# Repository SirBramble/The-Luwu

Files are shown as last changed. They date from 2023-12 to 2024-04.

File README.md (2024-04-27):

# The Luwu

ESP32 Board for RGB LED integration into Home Assistant
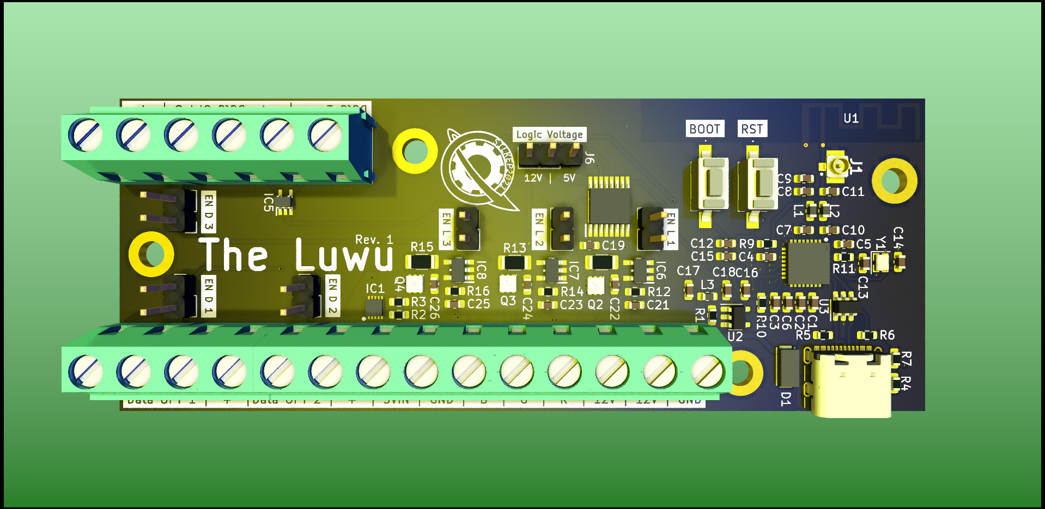
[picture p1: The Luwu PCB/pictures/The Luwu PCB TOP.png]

## Motivation

My 3D Printer has a standard RGB LED Strip installed in its enclosure. This Board allows me to control it with Home Assistant. There are easier and cheaper ways of doing this, but this Board also doubled as a test board for implementing Ideal Diodes and MOSFET drivers.

## Features

The Board uses a ESP32C3 to interface with Home Assistant. The ESP controls 3 RGB channels that are each capable of (in theory) driving 10A. These channels can also be mapped to control addressable RGB Strips, although this can only be done for all channels at once and **ONLY** if the level shifter logic voltage is set to 5V. There is also one dedicated addressable RGB Strip Port, that can be used at any time.

To accomplish these features, it needs a 5V supply to drive the logic and optionally the addressable LED Strips and a 12V supply to drive the non addressable Strip. To accomplish this in a 3D Printer environment a Voltage converter for the 24V Power Supply is needed. For this [the Supluwu](https://github.com/SirBramble/The-Supluwu) could be used.

## Integration into Home Assistant

ESP Home Config:

```yaml
esphome:
  name: NAME
  friendly_name: FRIENDLY_NAME

esp32:
  board: esp32-c3-devkitm-1
  framework:
    type: arduino

# Enable logging
logger:
  level: DEBUG
# Enable Home Assistant API
api:
  encryption:
    key: ""     #let this auto generate or set it yourself

ota:
  password: ""  #let this auto generate or set it yourself

wifi:
  ssid: !secret wifi_ssid
  password: !secret wifi_password

  # Enable fallback hotspot (captive portal) in case wifi connection fails
  ap:
    ssid: "FALLBACK_HOTSPOT_NAME"
    password: "SUPER_SECURE_PASSWORD123"

light:
  - platform: rgb
    id: oldstyle_rgb
    name: "Oldstyle RGB"
    red: gpio_red
    green: gpio_green
    blue: gpio_blue
    effects:
      - lambda:
          name: Rainbow
          update_interval: 5s
          lambda: |-
            static int state = 0;
            auto call = id(oldstyle_rgb).turn_on();
            call.set_transition_length(4000);
            if (state == 0) {
              call.set_rgb(1.0, 0.0, 0.0);
            } else if (state == 1) {
              call.set_rgb(1.0, 0.5, 0.0);
            } else if (state == 2) {
              call.set_rgb(1.0, 1.0, 0.0);
            } else if (state == 3) {
              call.set_rgb(0.5, 1.0, 0.0);
            } else if (state == 4) {
              call.set_rgb(0.0, 1.0, 0.0);
            } else if (state == 5) {
              call.set_rgb(0.0, 1.0, 0.5);
            } else if (state == 6) {
              call.set_rgb(0.0, 1.0, 1.0);
            } else if (state == 7) {
              call.set_rgb(0.0, 0.5, 1.0);
            } else if (state == 8) {
              call.set_rgb(0.0, 0.0, 1.0);
            } else if (state == 9) {
              call.set_rgb(0.5, 0.0, 1.0);
            } else if (state == 10) {
              call.set_rgb(1.0, 0.0, 1.0);
            } else if (state == 11) {
              call.set_rgb(1.0, 0.0, 0.5);
            }
            call.perform();
            state++;
            if (state == 12)
              state = 0;
      - lambda:
            name: Fast Rainbow
            update_interval: 1s
            lambda: |-
              static int state = 0;
              auto call = id(oldstyle_rgb).turn_on();
              call.set_transition_length(1000);
              if (state == 0) {
                call.set_rgb(1.0, 0.0, 0.0);
              } else if (state == 1) {
                call.set_rgb(1.0, 0.5, 0.0);
              } else if (state == 2) {
                call.set_rgb(1.0, 1.0, 0.0);
              } else if (state == 3) {
                call.set_rgb(0.5, 1.0, 0.0);
              } else if (state == 4) {
                call.set_rgb(0.0, 1.0, 0.0);
              } else if (state == 5) {
                call.set_rgb(0.0, 1.0, 0.5);
              } else if (state == 6) {
                call.set_rgb(0.0, 1.0, 1.0);
              } else if (state == 7) {
                call.set_rgb(0.0, 0.5, 1.0);
              } else if (state == 8) {
                call.set_rgb(0.0, 0.0, 1.0);
              } else if (state == 9) {
                call.set_rgb(0.5, 0.0, 1.0);
              } else if (state == 10) {
                call.set_rgb(1.0, 0.0, 1.0);
              } else if (state == 11) {
                call.set_rgb(1.0, 0.0, 0.5);
              }
              call.perform();
              state++;
              if (state == 12)
                state = 0;

# Example output entry (default)
output:
  - platform: ledc
    id: gpio_red
    pin: GPIO6
  - platform: ledc
    id: gpio_green
    pin: GPIO7
  - platform: ledc
    id: gpio_blue
    pin: GPIO10

#uncomment to enable
# Example output entry (modified)
#output:
#  - platform: ledc
#    id: gpio_red
#    pin: GPIO7
#  - platform: ledc
#    id: gpio_green
#    pin: GPIO10
#  - platform: ledc
#    id: gpio_blue
#    pin: GPIO6

captive_portal:
    
```

### Flashing firmware

I had some issues when flashing the Firmware.

This helped: [https://github.com/espressif/esp-idf/issues/9005](https://github.com/espressif/esp-idf/issues/9005)

## Schematic

The Schematic can be found here: [The Luwu PCB/print/The Luwu PCB.pdf](https://github.com/SirBramble/The-Luwu/blob/f4439437ab35bf7dc6665ce1337c5cff792b409b/The%20Luwu%20PCB/print/The%20Luwu%20PCB.pdf)

## Pictures



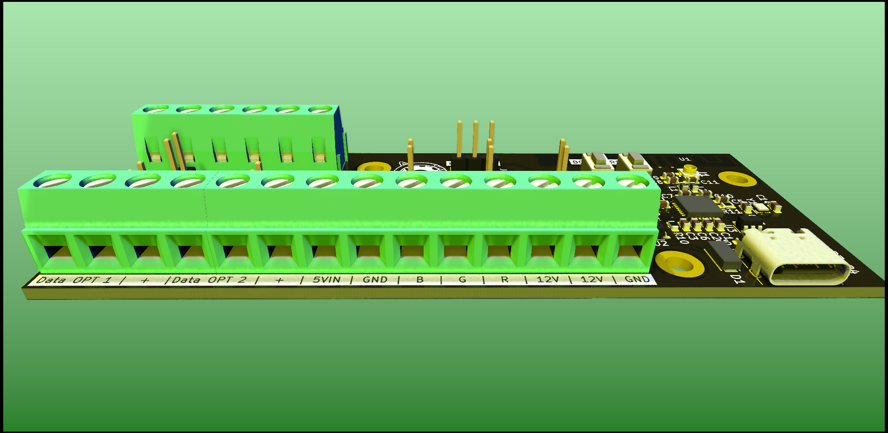
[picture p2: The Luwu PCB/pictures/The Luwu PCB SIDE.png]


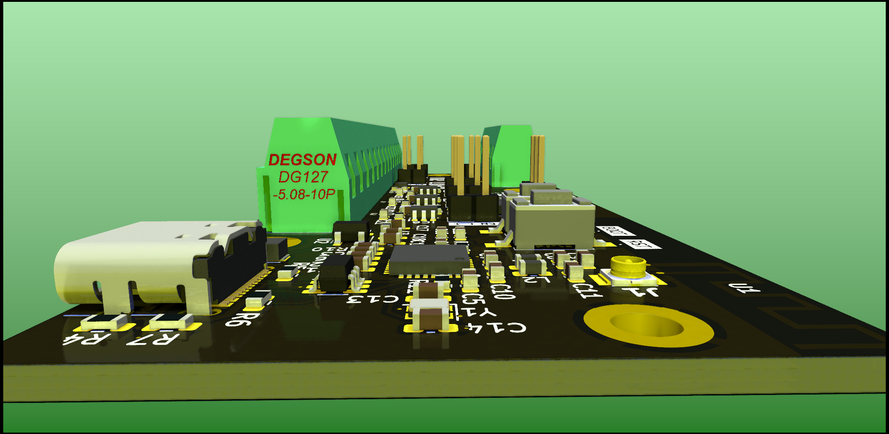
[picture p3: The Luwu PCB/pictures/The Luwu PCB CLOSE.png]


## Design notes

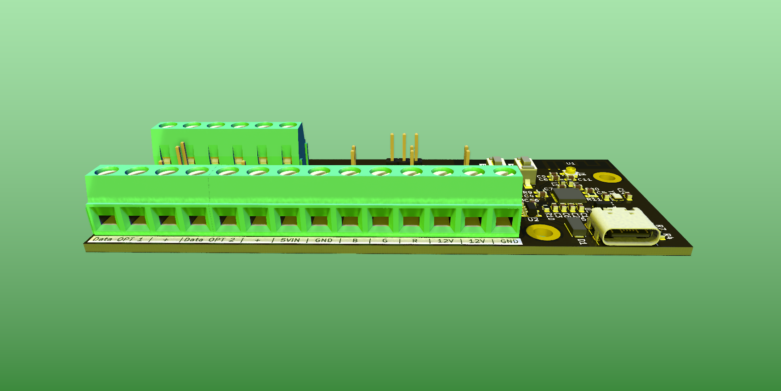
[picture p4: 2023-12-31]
The Luwu PCB/pictures/The Luwu PCB TN.png

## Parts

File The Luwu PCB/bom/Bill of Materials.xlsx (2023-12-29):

Designator | Footprint | Value | Description | Part Nr. | Quantity | Price/pcs. | Price
C10, C11 | 0603 | 3p3 | +/-0.5pF 50V Capacitor | 710-885012006048 (https://www.mouser.de/ProductDetail/710-885012006048) | 2 | 0.09 € | 0.19 €
C12, C15, C17, C18, C19, C2, C4, C5, C6, C7, C8 | 0603 | 100n | Generic 5% Capacitor | Generic | 11 | 0.01 € | 0.11 €
C13, C14 | 0603 | 10p | 5% 25V Capacitor | 710-885012006032 (https://www.mouser.de/ProductDetail/710-885012006032) | 2 | 0.09 € | 0.19 €
C16 | 0603 | 1u | Generic 20% Capacitor | Generic | 1 | 0.05 € | 0.05 €
C1, C3, C9, C21, C23, C25 | 0603 | 10uF | Generic 20% Capacitor | Generic | 6 | 0.05 € | 0.30 €
C22, C24, C26 | 0603 | 100nF | Generic 5% Capacitor | Generic | 3 | 0.01 € | 0.03 €
D1 | CD214A-B240LR | CD214A-B240LR | 40V 2A Diode | 652-CD214A-B240LR (https://www.mouser.de/ProductDetail/Bourns/CD214A-B240LR?qs=f9yNj16SXrLocD1dV%2FObRw%3D%3D) | 1 | 0.39 € | 0.39 €
IC1 | SON40P200X200X80-11N | TPS22953DSQR | Leistungsschalter IC | 595-TPS22953DSQR (https://www.mouser.de/ProductDetail/Texas-Instruments/TPS22953DSQR?qs=lGsJEpdjMw3By0yQoF%252B7vQ%3D%3D) | 1 | 0.77 € | 0.77 €
IC2 | QFN50P500X500X90-33N-D | ESP32-C3FH4 | ESP32C3 | 356-ESP32-C3FH4 (https://www.mouser.de/ProductDetail/Espressif-Systems/ESP32-C3FH4?qs=iLbezkQI%252BsgL5PSvEueYlQ%3D%3D) | 1 | 1.21 € | 1.21 €
IC4 | SOP65P640X120-16N | CD40109BPWR | 4-Bit Level shifter | 595-CD40109BPWR (https://www.mouser.de/ProductDetail/Texas-Instruments/CD40109BPWR?qs=LzFo6vGRJ4uizAk1qQcvPQ%3D%3D) | 1 | 0.44 € | 0.44 €
IC5 | SOT65P210X110-5N | SN74LV1T04DCKRG4 | 1-Bit Level shifter | 595-SN74LV1T04DCKRG4 (https://www.mouser.de/ProductDetail/Texas-Instruments/SN74LV1T04DCKRG4?qs=qSfuJ%252Bfl%2Fd4at7O15qky6A%3D%3D) | 1 | 0.21 € | 0.21 €
IC6, IC7, IC8 | SOT95P280X145-5N | UCC27519DBVR | Gate driver | 595-UCC27519DBVR (https://www.mouser.de/ProductDetail/Texas-Instruments/UCC27519DBVR?qs=Zv8nmyeoaKte1PBX4a6EXg%3D%3D) | 3 | 0.77 € | 2.32 €
J1 | 23370191 | 2337019-1 | MicroCoax connector | 571-2337019-1 (https://www.mouser.de/ProductDetail/TE-Connectivity/2337019-1?qs=l4Gc20tDgJIuN7nS9rJkJw%3D%3D) | 1 | 0.21 € | 0.21 €
J10 | TerminalBlock_bornier-3_P5.08mm | Neopixel Terminal out 3 | Generic Terminal Block | Generic | 1 | 0.05 € | 0.05 €
J2 | USB_C_Receptacle_GCT_USB4105-xx-A_16P_TopMnt_Horizontal | USB_C_Receptacle_USB2.0 | USB Type C 2.0 | 640-USB4105-GF-A (https://www.mouser.de/ProductDetail/640-USB4105-GF-A) | 1 | 0.74 € | 0.74 €
J3 | TerminalBlock_bornier-2_P5.08mm | 5V_IN | Generic Terminal Block | Generic | 1 | 0.05 € | 0.05 €
J4 | TerminalBlock_bornier-3_P5.08mm | Neopixel Terminal opt 1 | Generic Terminal Block | Generic | 1 | 0.05 € | 0.05 €
J5 | TerminalBlock_bornier-2_P5.08mm | 12V_IN | Generic Terminal Block | Generic | 1 | 0.05 € | 0.05 €
J6 | PinHeader_1x03_P2.54mm_Vertical | V SEL LS | Generic Pin Header | Generic | 1 | 0.05 € | 0.05 €
J7 | TerminalBlock_bornier-4_P5.08mm | Screw_Terminal_01x04 | Generic Terminal Block | Generic | 1 | 0.05 € | 0.05 €
J8 | TerminalBlock_bornier-3_P5.08mm | Neopixel Terminal | Generic Terminal Block | Generic | 1 | 0.05 € | 0.05 €
J9 | TerminalBlock_bornier-3_P5.08mm | Neopixel Terminal opt 2 | Generic Terminal Block | Generic | 1 | 0.05 € | 0.05 €
JP1, JP2, JP3, JP4, JP5, JP6 | PinHeader_1x02_P2.54mm_Vertical | Jumper_2_Open | Generic Pin Header | Generic | 6 | 0.05 € | 0.30 €
L1, L2, L3 | 0603 | 2n2 | 300mA 0,1ohm Inductor | 710-7847805220 (https://www.mouser.de/ProductDetail/710-7847805220) | 3 | 0.09 € | 0.28 €
Q2, Q3, Q4 | BUK7D2540EX | BUK7D25-40EX | N-MOSFET | 771-BUK7D25-40EX (https://eu.mouser.com/ProductDetail/Nexperia/BUK7D25-40EX?qs=%252BEew9%252B0nqrD3pISD4vyDrQ%3D%3D) | 3 | 0.25 € | 0.75 €
R1, R12, R14, R16 | 0603 | 10k | Generic 1% Resistor | Generic | 4 | 0.02 € | 0.08 €
R10, R5, R6, R9 | 0603 | 5k1 | Generic 1% Resistor | Generic | 4 | 0.02 € | 0.08 €
R11 | 0603 | 22 | 1% Resistor | 603-RC0603FR-1022RL (https://www.mouser.de/ProductDetail/603-RC0603FR-1022RL) | 1 | 0.09 € | 0.09 €
R13, R15, R8 | 1206 | 1.5 | Current shunt / Impulse limmiter | 652-CRM1206FX1R50ELF (https://www.mouser.de/ProductDetail/652-CRM1206FX1R50ELF) | 3 | 0.38 € | 1.14 €
R2 | 0603 | 100k | Generic 1% Resistor | Generic | 1 | 0.02 € | 0.02 €
R3 | 0603 | 20k | 1% Resistor | 603-RT0603FRE0720KL (https://www.mouser.de/ProductDetail/YAGEO/RT0603FRE0720KL?qs=8cPjvKtxWv65BAftULaFAQ%3D%3D) | 1 | 0.09 € | 0.09 €
R4 | 0603 | 15k | 1% Resistor | 603-RT0603FRE1315KL (https://www.mouser.de/ProductDetail/YAGEO/RT0603FRE1315KL?qs=%2Ff7pOCXLR5e5m0uEnyCcoA%3D%3D) | 1 | 0.09 € | 0.09 €
R7 | 0603 | 22k | 1% Resistor | 603-RT0603FRE1322KL (https://www.mouser.de/ProductDetail/YAGEO/RT0603FRE1322KL?qs=uTWeqZe11vwzRdhBSFPFcQ%3D%3D) | 1 | 0.09 € | 0.09 €
SW1, SW2 | PTS636SP50SMTRLFS | PTS636 SP50 | Tact. Switch 12V 50mA | 611-PTS636SP50SMTRLF (https://www.mouser.de/ProductDetail/CK/PTS636-SP50-SMTR-LFS?qs=vLWxofP3U2yQrwr1QnrRJw%3D%3D) | 2 | 0.14 € | 0.28 €
U2 | SOT-23-5 | AP2112K-3.3 | 3V3 Voltage Regulator | 621-AP2112K-3.3TRG1 (https://www.mouser.de/ProductDetail/Diodes-Incorporated/AP2112K-3.3TRG1?qs=x6A8l6qLYDDPYHosCdzh%2FA%3D%3D) | 1 | 0.31 € | 0.31 €
U3 | SOT-23-6 | USBLC6-2SC6 | TVS Diode Usb | 511-USBLC6-2SC6 (https://www.mouser.de/ProductDetail/STMicroelectronics/USBLC6-2SC6?qs=po45yt2pPpu%2FhNIlwQdTlg%3D%3D) | 1 | 0.54 € | 0.54 €
Y1 | Crystal_SMD_2016-4Pin_2.0x1.6mm | ECS-400-10-37B2-CKM-TR | Crystal 40MHz 10pF | 520-400-10-37B2CKMTR (https://www.mouser.de/ProductDetail/ECS/ECS-400-10-37B2-CKM-TR?qs=QNEnbhJQKvYTTE6TC4Pr1w%3D%3D) | 1 | 0.35 € | 0.35 €
 |  |  |  |  |  |  | 12.07 €

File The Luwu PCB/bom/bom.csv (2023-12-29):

Designator | Footprint | Quantity | Value | LCSC Part #
C1, C3, C9 | 0603 | 3 | 10u
C10, C11 | 0603 | 2 | 3p3
C12, C15, C17, C18, C19, C2, C4, C5, C6, C7, C8 | 0603 | 11 | 100n
C13, C14 | 0603 | 2 | 10p
C16 | 0603 | 1 | 1u
C21, C23, C25 | 0603 | 3 | 10uF
C22, C24, C26 | 0603 | 3 | 100nF
D1 | CD214A-B240LR | 1 | CD214A-B240LR
IC1 | SON40P200X200X80-11N | 1 | TPS22953DSQR
IC2 | QFN50P500X500X90-33N-D | 1 | ESP32-C3FH4
IC4 | SOP65P640X120-16N | 1 | CD40109BPWR
IC5 | SOT65P210X110-5N | 1 | SN74LV1T04DCKRG4
IC6, IC7, IC8 | SOT95P280X145-5N | 3 | UCC27519DBVR
J1 | 23370191 | 1 | 2337019-1
J10 | TerminalBlock_bornier-3_P5.08mm | 1 | Neopixel Terminal out 3
J2 | USB_C_Receptacle_GCT_USB4105-xx-A_16P_TopMnt_Horizontal | 1 | USB_C_Receptacle_USB2.0
J3 | TerminalBlock_bornier-2_P5.08mm | 1 | 5V_IN
J4 | TerminalBlock_bornier-3_P5.08mm | 1 | Neopixel Terminal opt 1
J5 | TerminalBlock_bornier-2_P5.08mm | 1 | 12V_IN
J6 | PinHeader_1x03_P2.54mm_Vertical | 1 | V SEL LS
J7 | TerminalBlock_bornier-4_P5.08mm | 1 | Screw_Terminal_01x04
J8 | TerminalBlock_bornier-3_P5.08mm | 1 | Neopixel Terminal
J9 | TerminalBlock_bornier-3_P5.08mm | 1 | Neopixel Terminal opt 2
JP1, JP2, JP3, JP4, JP5, JP6 | PinHeader_1x02_P2.54mm_Vertical | 6 | Jumper_2_Open
L1, L2, L3 | 0603 | 3 | 2n2
Q2, Q3, Q4 | BUK7D2540EX | 3 | BUK7D25-40EX
R1, R12, R14, R16 | 0603 | 4 | 10k
R10, R5, R6, R9 | 0603 | 4 | 5k1
R11 | 0603 | 1 | 22
R13, R15, R8 | 1206 | 3 | 1.5
R2 | 0603 | 1 | 100k
R3 | 0603 | 1 | 20k
R4 | 0603 | 1 | 15k
R7 | 0603 | 1 | 22k
SW1, SW2 | PTS636SP50SMTRLFS | 2 | PTS636 SP50
U2 | SOT-23-5 | 1 | AP2112K-3.3
U3 | SOT-23-6 | 1 | USBLC6-2SC6
Y1 | Crystal_SMD_2016-4Pin_2.0x1.6mm | 1 | ECS-400-10-37B2-CKM-TR

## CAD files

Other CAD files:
The Luwu PCB/plot/The Luwu PCB-B_Silkscreen.dxf
The Luwu PCB/plot/The Luwu PCB-F_Silkscreen.dxf

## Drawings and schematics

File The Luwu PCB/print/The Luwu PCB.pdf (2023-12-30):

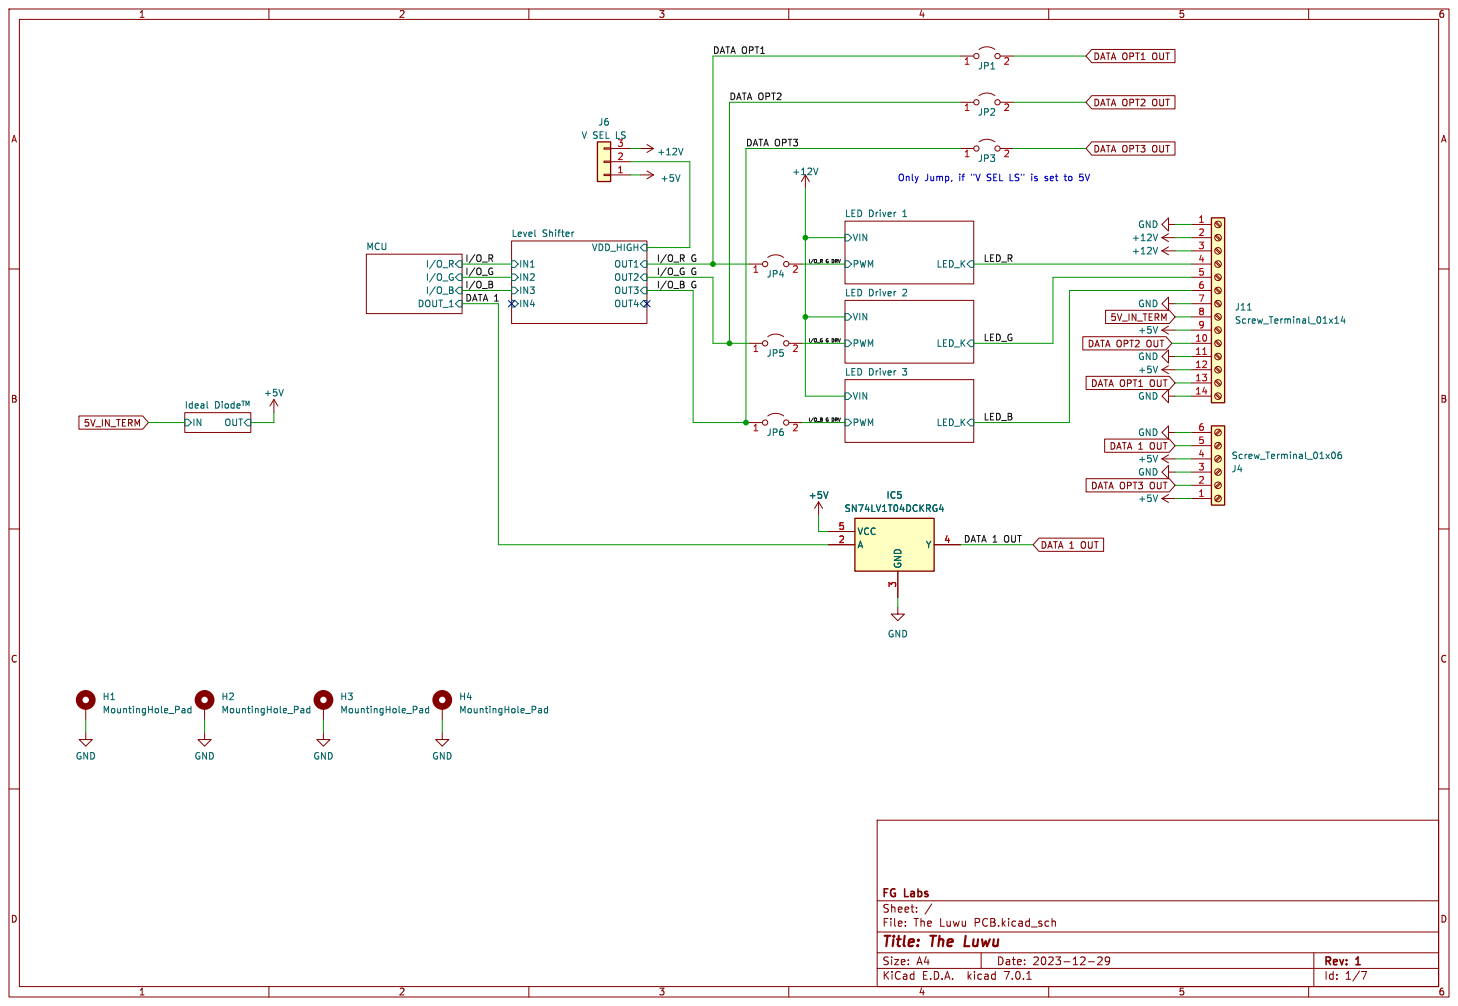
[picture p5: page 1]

DATA OPT1 OUT DATA OPT1 OUT DATA OPT3 OUT DATA OPT2 OUT

LED_B DATA 1 OUT Only Jump, if "V SEL LS" is set to 5V

Id: 1/7 Title: The Luwu

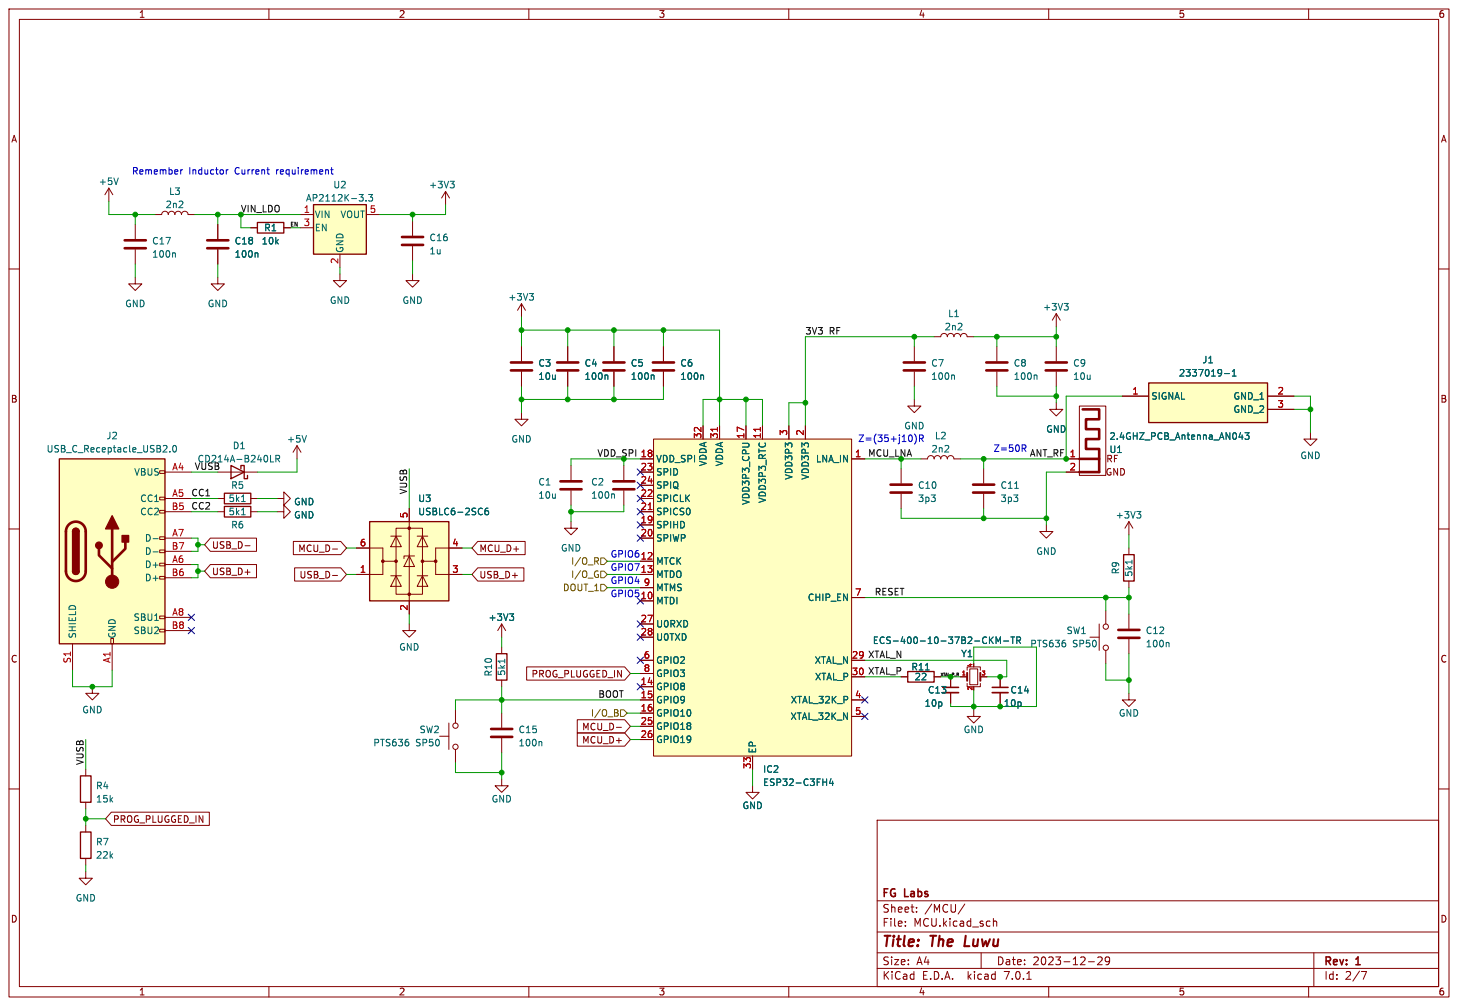
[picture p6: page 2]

2 SPIWP 20 SPICS0 21 SPICLK 22 SPID 23 SPIQ 24 GPIO18 25 GPIO19 26 U0RXD 27 U0TXD 28 XTAL_N 29 VDD3P3

3 XTAL_P 30 VDDA 31 VDDA 32 EP 33 XTAL_32K_P 4 XTAL_32K_N 5 GPIO2 6 CHIP_EN 7 GPIO3 8 MTMS 9

3 XTAL_P 30 VDDA 31 VDDA 32 EP 33 XTAL_32K_P 4 XTAL_32K_N 5 GPIO2 6 CHIP_EN 7 GPIO3 8 MTMS 9 GND

4 Y1 ECS-400-10-37B2-CKM-TR GND A1 VBUS A4 CC1 A5 D+ A6 D- A7 SBU1 A8 CC2 B5 D+ B6 D- B7 SBU2 B8 SHIELD S1

Id: 2/7 Title: The Luwu

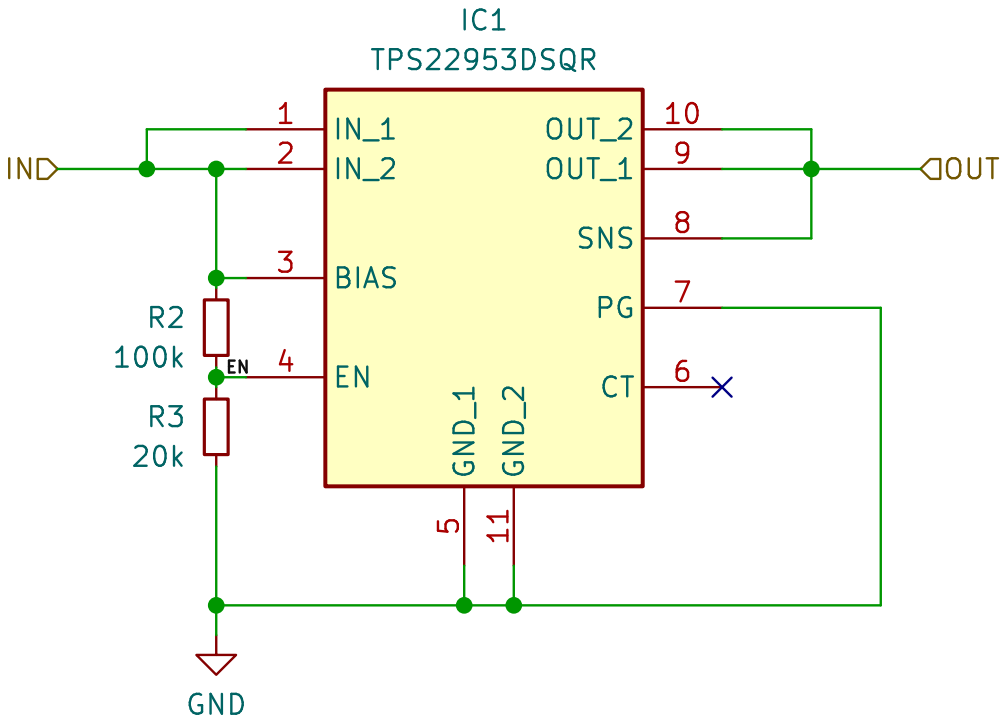
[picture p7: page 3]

Id: 3/7 Title: The Luwu

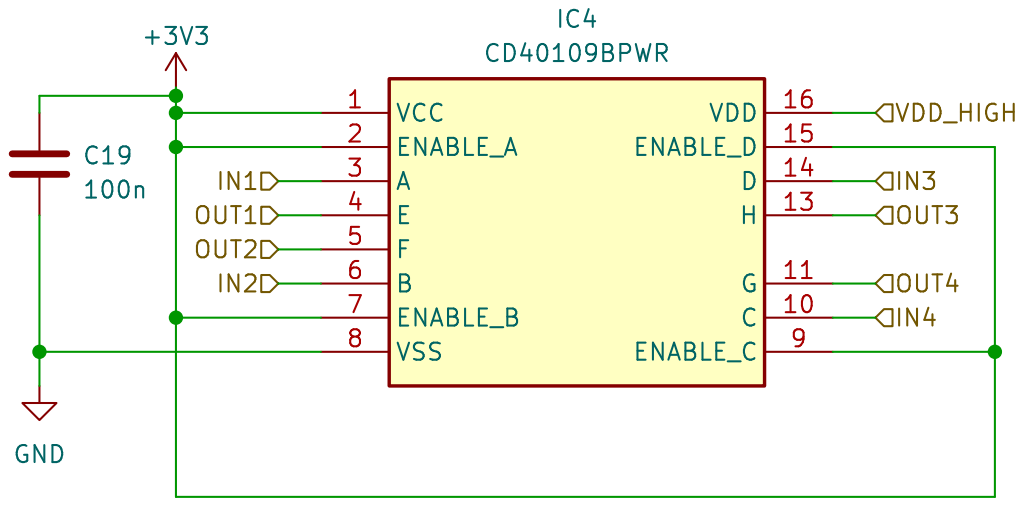
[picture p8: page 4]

Id: 5/7 Title: The Luwu

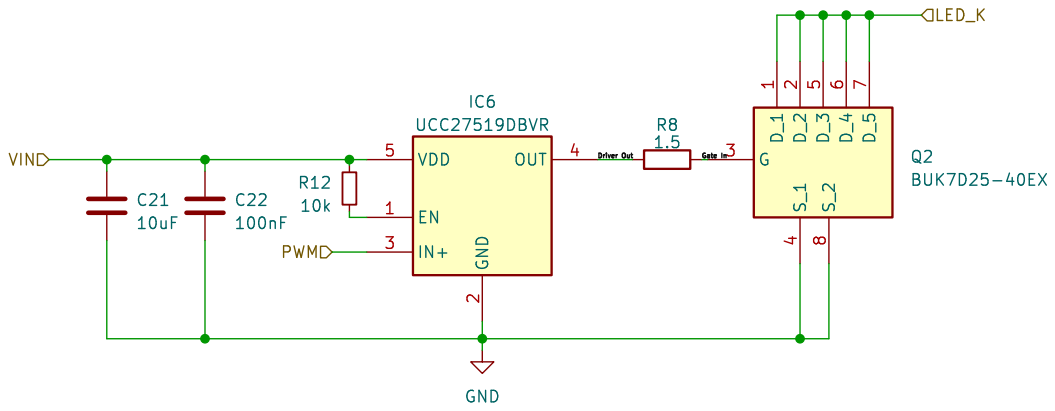
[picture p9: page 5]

Id: 6/7 Title: The Luwu

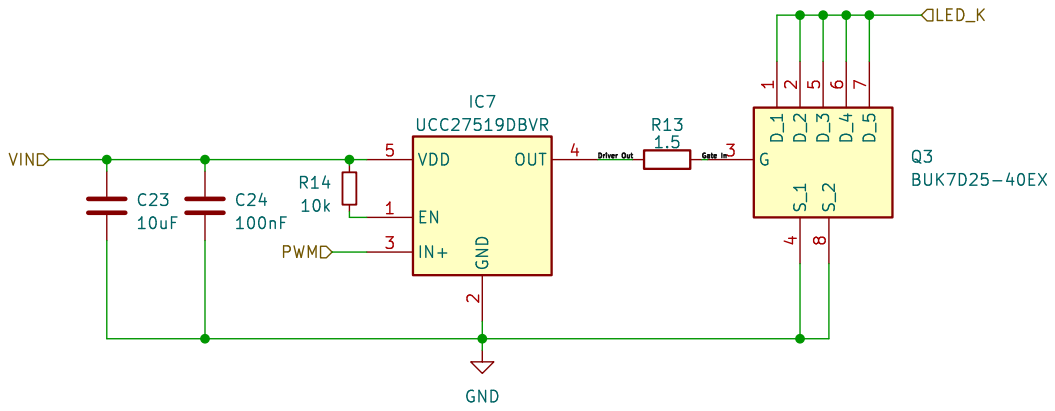
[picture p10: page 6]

Id: 7/7 Title: The Luwu

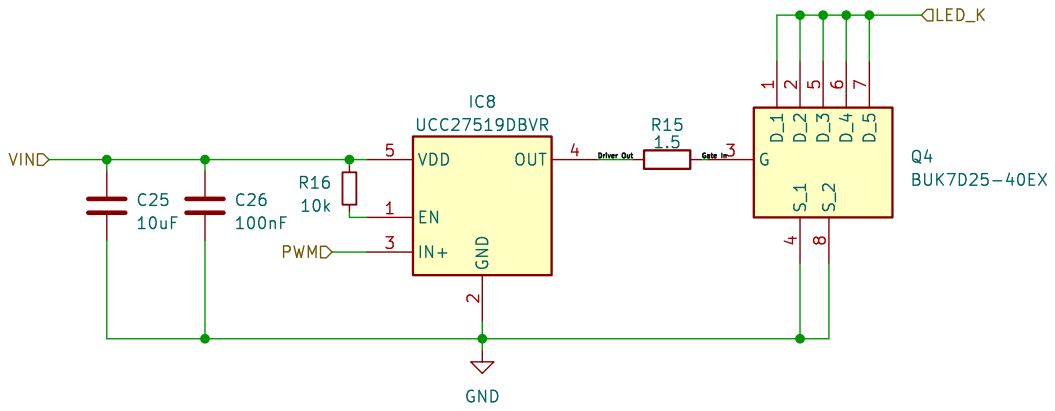
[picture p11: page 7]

Id: 8/7 Title: The Luwu

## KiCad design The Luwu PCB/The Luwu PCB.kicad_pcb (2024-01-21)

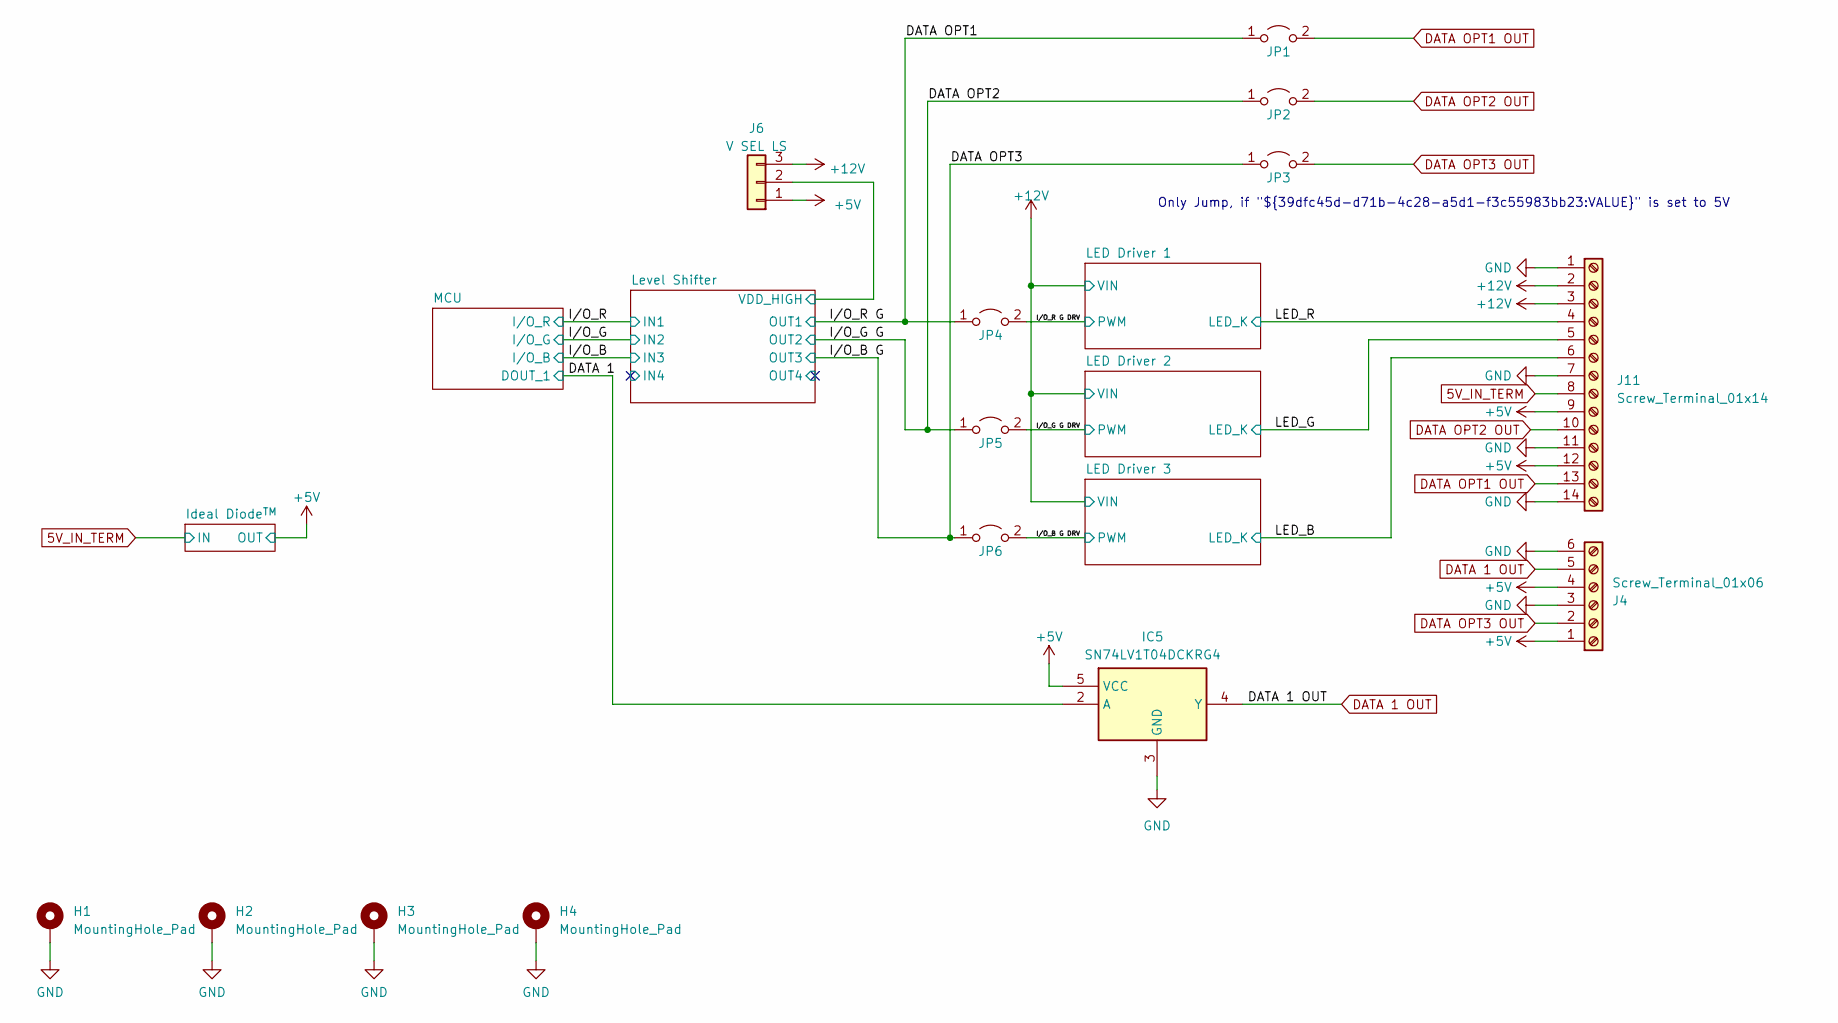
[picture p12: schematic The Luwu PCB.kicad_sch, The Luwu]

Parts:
H1, H2, H3, H4: MountingHole_Pad; MountingHole_3.2mm_M3_DIN965_Pad
IC5: SN74LV1T04DCKRG4; SOT65P210X110-5N; Mouser Part Number 595-SN74LV1T04DCKRG4
J4: Screw_Terminal_01x06; TerminalBlock_bornier-6_P5.08mm
J6: V SEL LS; PinHeader_1x03_P2.54mm_Vertical
J11: Screw_Terminal_01x14; TerminalBlock_bornier-14_P5.08mm
JP1, JP2, JP3, JP4, JP5, JP6: Jumper_2_Open; PinHeader_1x02_P2.54mm_Vertical

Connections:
5V_IN_TERM: J11.8; also elsewhere on the board
+5V: IC5.5 (VCC), J4.1, J4.4, J6.1, J11.9, J11.12; also elsewhere on the board
+12V: J6.3, J11.2, J11.3; also elsewhere on the board
/DATA 1: IC5.2 (A); also elsewhere on the board
/DATA OPT1: JP1.1 (A), JP4.1 (A); also elsewhere on the board
/DATA OPT2: JP2.1 (A), JP5.1 (A); also elsewhere on the board
/DATA OPT3: JP3.1 (A), JP6.1 (A); also elsewhere on the board
/I/O_B G DRV: JP6.2 (B); also elsewhere on the board
/I/O_G G DRV: JP5.2 (B); also elsewhere on the board
/I/O_R G DRV: JP4.2 (B); also elsewhere on the board
/LED_B: J11.6; also elsewhere on the board
/LED_G: J11.5; also elsewhere on the board
/LED_R: J11.4; also elsewhere on the board
/Level Shifter/VDD_HIGH: J6.2; also elsewhere on the board
DATA 1 OUT: IC5.4 (Y), J4.5
DATA OPT1 OUT: J11.13, JP1.2 (B)
DATA OPT2 OUT: J11.10, JP2.2 (B)
DATA OPT3 OUT: J4.2, JP3.2 (B)
GND: H1.1, H2.1, H3.1, H4.1, IC5.3 (GND), J4.3, J4.6, J11.1, J11.7, J11.11, J11.14; also elsewhere on the board

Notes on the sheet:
Only Jump, if "${39dfc45d-d71b-4c28-a5d1-f3c55983bb23:VALUE}" is set to 5V

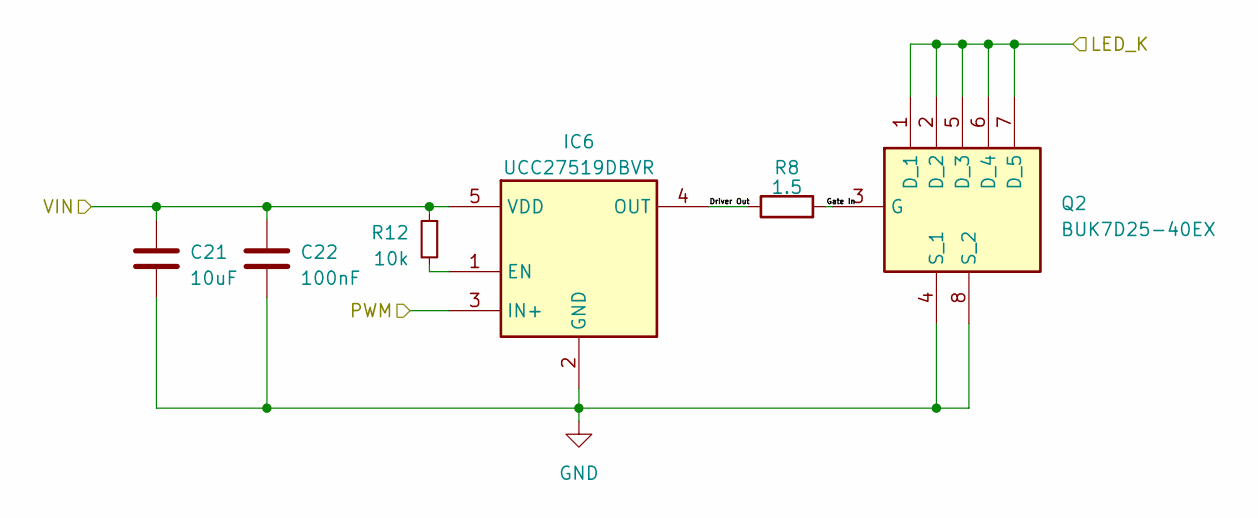
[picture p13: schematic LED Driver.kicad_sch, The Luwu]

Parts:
C21: 10uF; C_0603_1608Metric
C22: 100nF; C_0603_1608Metric
IC6: UCC27519DBVR; SOT95P280X145-5N; Mouser Part Number 595-UCC27519DBVR
Q2: BUK7D25-40EX; BUK7D2540EX; Mouser Part Number 771-BUK7D25-40EX
R8: 1.5; R_1206_3216Metric
R12: 10k; R_0603_1608Metric

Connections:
+12V: C21.1, C22.1, IC6.5 (VDD), R12.1; also elsewhere on the board
/I/O_R G DRV: IC6.3 (IN+); also elsewhere on the board
/LED Driver 1/Driver Out: IC6.4 (OUT), R8.1
/LED Driver 1/Gate In: Q2.3 (G), R8.2
/LED_R: Q2.1 (D_1), Q2.2 (D_2), Q2.5 (D_3), Q2.6 (D_4), Q2.7 (D_5); also elsewhere on the board
GND: C21.2, C22.2, IC6.2 (GND), Q2.4 (S_1), Q2.8 (S_2); also elsewhere on the board
unnamed: IC6.1 (EN), R12.2

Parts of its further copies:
C23, C25: 10uF; C_0603_1608Metric
C24, C26: 100nF; C_0603_1608Metric
IC7, IC8: UCC27519DBVR; SOT95P280X145-5N; Mouser Part Number 595-UCC27519DBVR
Q3, Q4: BUK7D25-40EX; BUK7D2540EX; Mouser Part Number 771-BUK7D25-40EX
R13, R15: 1.5; R_1206_3216Metric
R14, R16: 10k; R_0603_1608Metric

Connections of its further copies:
+12V: C23.1, C24.1, C25.1, C26.1, IC7.5 (VDD), IC8.5 (VDD), R14.1, R16.1; also elsewhere on the board
/I/O_B G DRV: IC8.3 (IN+); also elsewhere on the board
/I/O_G G DRV: IC7.3 (IN+); also elsewhere on the board
/LED Driver 2/Driver Out: IC7.4 (OUT), R13.1
/LED Driver 2/Gate In: Q3.3 (G), R13.2
/LED Driver 3/Driver Out: IC8.4 (OUT), R15.1
/LED Driver 3/Gate In: Q4.3 (G), R15.2
/LED_B: Q4.1 (D_1), Q4.2 (D_2), Q4.5 (D_3), Q4.6 (D_4), Q4.7 (D_5); also elsewhere on the board
/LED_G: Q3.1 (D_1), Q3.2 (D_2), Q3.5 (D_3), Q3.6 (D_4), Q3.7 (D_5); also elsewhere on the board
GND: C23.2, C24.2, C25.2, C26.2, IC7.2 (GND), IC8.2 (GND), Q3.4 (S_1), Q3.8 (S_2), Q4.4 (S_1), Q4.8 (S_2); also elsewhere on the board
unnamed: IC7.1 (EN), R14.2
unnamed: IC8.1 (EN), R16.2

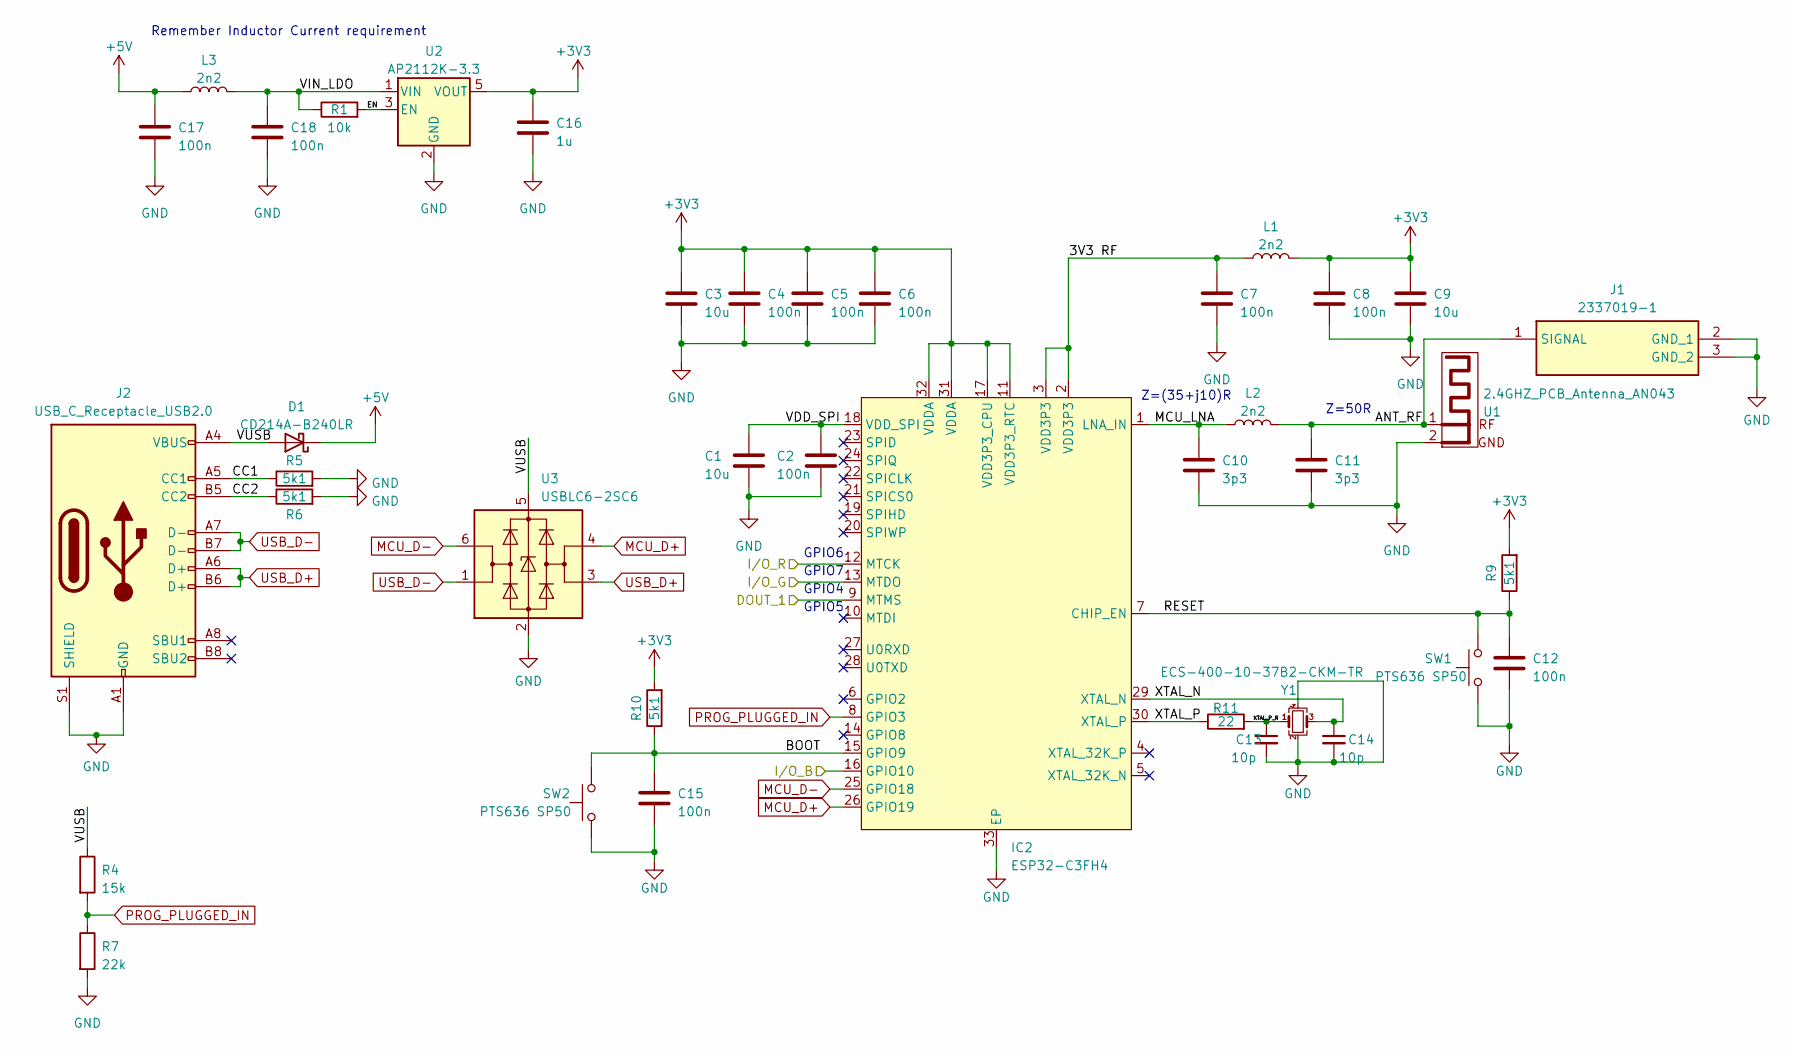
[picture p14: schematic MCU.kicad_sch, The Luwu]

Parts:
C1, C3, C9: 10u; C_0603_1608Metric
C2, C4, C5, C6, C7, C8, C12, C15, C17, C18: 100n; C_0603_1608Metric
C10, C11: 3p3; C_0603_1608Metric
C13, C14: 10p; C_0603_1608Metric
C16: 1u; C_0603_1608Metric
D1: CD214A-B240LR
IC2: ESP32-C3FH4; QFN50P500X500X90-33N-D; Mouser Part Number 356-ESP32-C3FH4
J1: 2337019-1; 23370191; Mouser Part Number 571-2337019-1
J2: USB_C_Receptacle_USB2.0; USB_C_Receptacle_GCT_USB4105-xx-A_16P_TopMnt_Horizontal
L1, L2, L3: 2n2; L_0603_1608Metric
R1: 10k; R_0603_1608Metric
R4: 15k; R_0603_1608Metric
R5, R6, R9, R10: 5k1; R_0603_1608Metric
R7: 22k; R_0603_1608Metric
R11: 22; R_0603_1608Metric
SW1, SW2: PTS636 SP50; PTS636SP50SMTRLFS
U1: 2.4GHZ_PCB_Antenna_AN043; 2.4GHZ PCB Antenna AN043
U2: AP2112K-3.3; SOT-23-5
U3: USBLC6-2SC6; SOT-23-6
Y1: ECS-400-10-37B2-CKM-TR; Crystal_SMD_2016-4Pin_2.0x1.6mm

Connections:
+3V3: C3.1, C4.1, C5.1, C6.1, C8.1, C9.1, C16.1, IC2.11 (VDD3P3_RTC), IC2.17 (VDD3P3_CPU), IC2.31 (VDDA), IC2.32 (VDDA), L1.2, R9.2, R10.2, U2.5 (VOUT); also elsewhere on the board
+5V: C17.1, D1.1 (K), L3.1; also elsewhere on the board
/DATA 1: IC2.9 (MTMS); also elsewhere on the board
/I/O_B: IC2.16 (GPIO10); also elsewhere on the board
/I/O_G: IC2.13 (MTDO); also elsewhere on the board
/I/O_R: IC2.12 (MTCK); also elsewhere on the board
/MCU/3V3 RF: C7.1, IC2.2 (VDD3P3), IC2.3 (VDD3P3), L1.1
/MCU/ANT_RF: C11.1, J1.1 (SIGNAL), L2.2, U1.1
/MCU/BOOT: C15.1, IC2.15 (GPIO9), R10.1, SW2.2
/MCU/CC1: J2.A5 (CC1), R5.1
/MCU/CC2: J2.B5 (CC2), R6.1
/MCU/EN: R1.2, U2.3 (EN)
/MCU/MCU_LNA: C10.1, IC2.1 (LNA_IN), L2.1
/MCU/RESET: C12.1, IC2.7 (CHIP_EN), R9.1, SW1.2
/MCU/VDD_SPI: C1.1, C2.1, IC2.18 (VDD_SPI)
/MCU/VIN_LDO: C18.1, L3.2, R1.1, U2.1 (VIN)
/MCU/VUSB: D1.2 (A), J2.A4 (VBUS), J2.A9 (VBUS), J2.B4 (VBUS), J2.B9 (VBUS), R4.1, U3.5 (VBUS)
/MCU/XTAL_N: C14.1, IC2.29 (XTAL_N), Y1.3
/MCU/XTAL_P: IC2.30 (XTAL_P), R11.1
/MCU/XTAL_P_R: C13.1, R11.2, Y1.1
GND: C1.2, C2.2, C3.2, C4.2, C5.2, C6.2, C7.2, C8.2, C9.2, C10.2, C11.2, C12.2, C13.2, C14.2, C15.2, C16.2, C17.2, C18.2, IC2.33 (EP), J1.2 (GND_1), J1.3 (GND_2), J2.A1 (GND), J2.A12 (GND), J2.B1 (GND), J2.B12 (GND), J2.S1 (SHIELD), R5.2, R6.2, R7.2, SW1.1, SW2.1, U1.2, U2.2 (GND), U3.2 (GND), Y1.2, Y1.4; also elsewhere on the board
MCU_D+: IC2.26 (GPIO19), U3.4 (I/O2)
MCU_D-: IC2.25 (GPIO18), U3.6 (I/O1)
PROG_PLUGGED_IN: IC2.8 (GPIO3), R4.2, R7.1
USB_D+: J2.A6 (D+), J2.B6 (D+), U3.3 (I/O2)
USB_D-: J2.A7 (D-), J2.B7 (D-), U3.1 (I/O1)

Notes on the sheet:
GPIO5
Remember Inductor Current requirement
GPIO4
Z=50R
GPIO7
Z=(35+j10)R
GPIO6

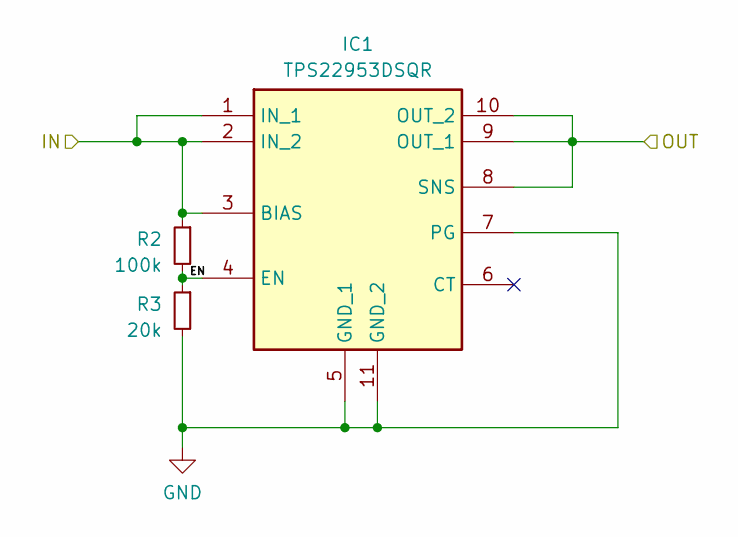
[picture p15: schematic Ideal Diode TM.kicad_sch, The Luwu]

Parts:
IC1: TPS22953DSQR; SON40P200X200X80-11N; Mouser Part Number 595-TPS22953DSQR
R2: 100k; R_0603_1608Metric
R3: 20k; R_0603_1608Metric

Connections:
5V_IN_TERM: IC1.1 (IN_1), IC1.2 (IN_2), IC1.3 (BIAS), R2.1; also elsewhere on the board
+5V: IC1.8 (SNS), IC1.9 (OUT_1), IC1.10 (OUT_2); also elsewhere on the board
/Ideal Diode^{TM}/EN: IC1.4 (EN), R2.2, R3.1
GND: IC1.5 (GND_1), IC1.7 (PG), IC1.11 (GND_2), R3.2; also elsewhere on the board

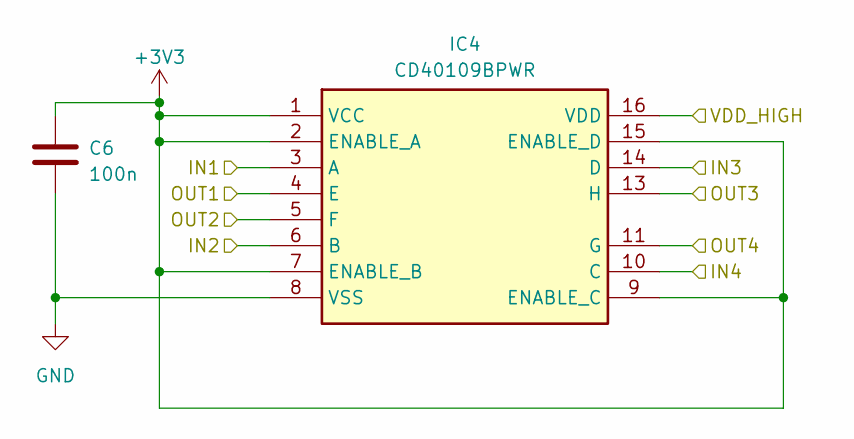
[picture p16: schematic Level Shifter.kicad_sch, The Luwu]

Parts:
C6: 100n; C_0603_1608Metric
IC4: CD40109BPWR; SOP65P640X120-16N; Mouser Part Number 595-CD40109BPWR

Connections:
+3V3: C6.1, IC4.1 (VCC), IC4.2 (ENABLE_A), IC4.7 (ENABLE_B), IC4.9 (ENABLE_C), IC4.15 (ENABLE_D); also elsewhere on the board
/DATA OPT1: IC4.4 (E); also elsewhere on the board
/DATA OPT2: IC4.5 (F); also elsewhere on the board
/DATA OPT3: IC4.13 (H); also elsewhere on the board
/I/O_B: IC4.14 (D); also elsewhere on the board
/I/O_G: IC4.6 (B); also elsewhere on the board
/I/O_R: IC4.3 (A); also elsewhere on the board
/Level Shifter/IN4: IC4.10 (C)
/Level Shifter/OUT4: IC4.11 (G)
/Level Shifter/VDD_HIGH: IC4.16 (VDD); also elsewhere on the board
GND: C6.2, IC4.8 (VSS); also elsewhere on the board

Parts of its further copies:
C19: 100n; C_0603_1608Metric

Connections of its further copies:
+3V3: C19.1; also elsewhere on the board
GND: C19.2; also elsewhere on the board

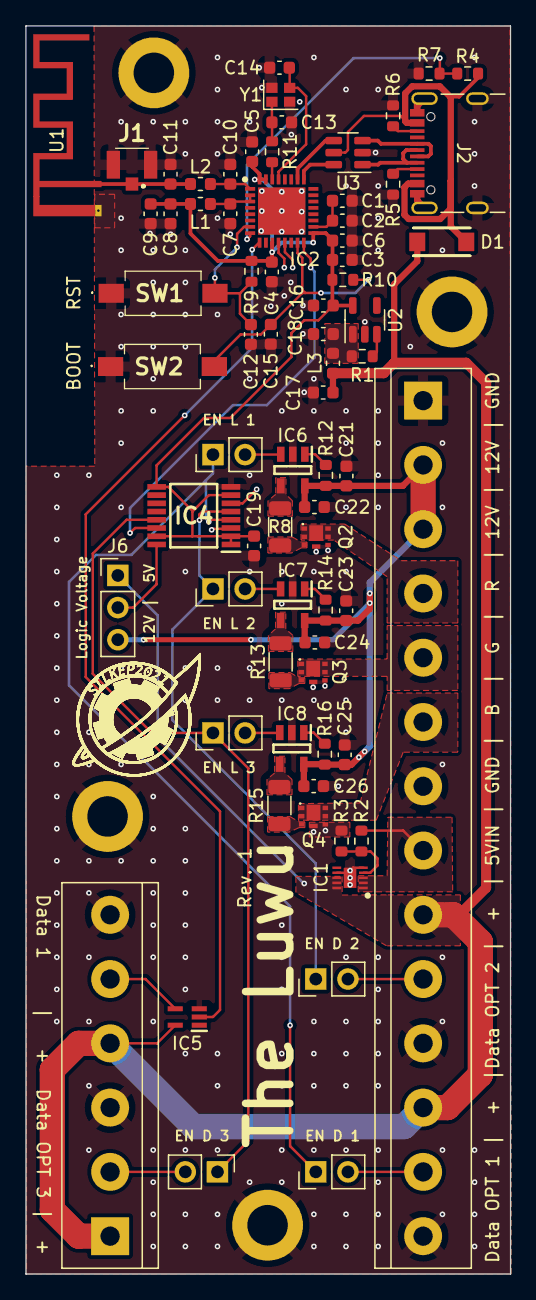
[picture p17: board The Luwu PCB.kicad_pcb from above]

Board: 4 copper layers, 38.3 x 98.7 mm, 76 parts (0 on the bottom side), 52 nets.

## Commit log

2023-12-30 added shortcut for schematic
2023-12-30 updated schematic print
2023-12-30 updated size
    [The Luwu PCB.kicad_pcb, The Luwu PCB.kicad_sch, bom.csv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]
2024-01-21 added 3D
    [The Luwu PCB-B_Silkscreen.dxf, The Luwu PCB-F_Silkscreen.dxf, The Luwu PCB.kicad_pcb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]
